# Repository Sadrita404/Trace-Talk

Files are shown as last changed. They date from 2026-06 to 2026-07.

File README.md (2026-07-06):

<div align="center">
  <table border="0" cellpadding="0" cellspacing="0">
    <tr>
      <td align="center" style="background: #ffffff; border: 1px solid #d0d7de; border-radius: 12px; padding: 16px; box-shadow: 0 4px 12px rgba(0,0,0,0.05);">
        Rough Layout For The PCB
        <div style="margin-top: 12px; font-family: -apple-system, BlinkMacSystemFont, 'Segoe UI', Helvetica, Arial, sans-serif; font-size: 13px; color: #57606a; font-weight: 500;">
      </td>
    </tr>
  </table>
</div>

| Title | Trace Talk |
| :-- | :---|
|Author |Sadrita Neogi|

## What's this?

TraceTalk is a walkie-talkie small radio  powered by a custom PCB and an ATMEGA328P (Arduino) microcontroller. It features a built-in rechargeable battery that charges with any standard USB-C cable and power brick. I also put together a custom enclosure to keep the PCB safe.
## Why I built it ?

From a very starting point, I walkie talkie due to their principle of work like the transmission between two devices without any internet connection and we are able to talk to each other. This made me fascinated, and I also wanted to make one for myself, but in general, the walkie-talkie that we see is balki and heavy so I made it pocket size, slim, walkie-talkie that can be connected via headphone and we can use it.

## How to use ?

To use the walkie-talkie, just plug any headphones with a mic into the 3.5mm jack, then flip the switch on the left side of the board and the LED will turn on. Just press and hold the button on the board to transmit your voice, and any nearby walkie-talkies will pick it up and play the audio. No pairing or setup needed.

The battery will lasts for about 4 hours( according to my calculation that I have made by going to the data sheet of each components, and this is what I approximately estimated ) and charges with any USB-C cable and power source. While it's charging, an LED near the USB port will light up, and it'll turn off once the battery is fully charged. Just a heads-up: the headphones you use can affect the audio quality, so you might want to try a few different pairs to see what works best.

## Technical Description
This project runs on an ATMEGA328P microcontroller sitting on a custom PCB (TraceTalk). It sends all the audio data through an NRF24L01 radio module. The ATMEGA328P runs at 3.3V and 8MHz, and you can program it right through the Arduino IDE. While you could technically use an external programmer like a USBTinyISP, the Arduino IDE is definitely the easiest and most straightforward way to go.

For the radio, I used the SMD version of the NRF24L01 to keep the board as small as possible. It gets a maximum range of about 100 meters.

The LiPo battery is soldered straight onto the board's battery terminals. I’d recommend picking up a battery with a 100-150mAh capacity—that’s the sweet spot for getting the best results.

<div align="center">

| | Building Process | |
| :---: | :---: | :---: |
|  |  |  |
|  |  |  |
|  |  |  |

Screenshot 2026-06-30 at 8 57 12 PM

<div align="center">
  <h2> Final Look </h2>
  <table border="0" cellpadding="10" cellspacing="0" style="border-collapse: collapse;">
    <tr>
      <!-- FRONT SIDE CARD -->
      <td align="center" valign="top" width="50%" style="background: #ffffff; border: 1px solid #d0d7de; border-radius: 12px; padding: 16px; box-shadow: 0 4px 12px rgba(0,0,0,0.05);">
        Front Side View
        <div style="margin-top: 12px; font-family: -apple-system, BlinkMacSystemFont, 'Segoe UI', Helvetica, Arial, sans-serif; font-size: 13px; color: #57606a; font-weight: 600; text-transform: uppercase; letter-spacing: 0.5px;">
          ▲ Front Side View
        </div>
      </td>
      <!-- SPACER FOR GITHUB MOBILE DEGRADATION -->
      <td width="2%">&nbsp;</td>
      <!-- BACK SIDE CARD -->
      <td align="center" valign="top" width="50%" style="background: #ffffff; border: 1px solid #d0d7de; border-radius: 12px; padding: 16px; box-shadow: 0 4px 12px rgba(0,0,0,0.05);">
        Back Side View
        <div style="margin-top: 12px; font-family: -apple-system, BlinkMacSystemFont, 'Segoe UI', Helvetica, Arial, sans-serif; font-size: 13px; color: #57606a; font-weight: 600; text-transform: uppercase; letter-spacing: 0.5px;">
          ▲ Back Side View
        </div>
      </td>
    </tr>
  </table>
</div>
</div>

<div align="center">
  <h2> Bill of Materials </h2>
</div>

| Name | Purpose | Qty | Total (USD) | Link | Distributor |
| :--- | :--- | :---: | :---: | :---: | :--- |
| PCBA SMT Assembly | SMT assembly of all SMD components | 5 | 51.93 | — | JLCPCB |
| PCB Fabrication (Trace Talk) | 2-layer PCB — the board itself | 5 | 2.00 | — | JLCPCB |
| C10,C11,C3 | 100nF 50V X7R ±10% 0805 MLCC | 25 | 0.87 | [Link](https://lcsc.com/product-detail/C476766.html) | JLCPCB |
| D1,D2 | Red Water Clear 0805 LED Indication | 22 | 0.31 | [Link](https://lcsc.com/product-detail/C434431.html) | JLCPCB |
| J1 | 1A 3.5mm Headphone Jack 30V SMD R/A | 6 | 0.63 | [Link](https://lcsc.com/product-detail/C521460.html) | JLCPCB |
| J2 | 0.3mm 1mm 5P Right Angle Top Contact FFC/FPC Connector | 6 | 0.59 | [Link](https://lcsc.com/product-detail/C262360.html) | JLCPCB |
| R1,R5,R6 | 330Ω 125mW 150V Thick Film Resistor ±5% 0805 | 25 | 0.07 | [Link](https://lcsc.com/product-detail/C25306.html) | JLCPCB |
| R2,R3 | 5.1kΩ 125mW 150V Thick Film Resistor ±1% 0805 | 10 | 0.04 | [Link](https://lcsc.com/product-detail/C27834.html) | JLCPCB |
| R10,R4 | 1kΩ 125mW 150V Thick Film Resistor ±1% 0805 | 20 | 0.09 | [Link](https://lcsc.com/product-detail/C95781.html) | JLCPCB |
| R11,R12,R13,R7,R8,R9 | 10kΩ 125mW 150V Thick Film Resistor ±1% 0805 | 30 | 0.13 | [Link](https://lcsc.com/product-detail/C17414.html) | JLCPCB |
| C1,C2,C4,C5,C6,C8 | 10V 10uF X5R ±10% 0805 MLCC | 40 | 7.11 | [Link](https://lcsc.com/product-detail/C17024.html) | JLCPCB |
| SW1 | PCM12SMTR SPDT Surface Mount Vertical Slide Switch | 5 | 6.23 | [Link](https://lcsc.com/product-detail/C221841.html) | JLCPCB |
| SW2 | PTS645 Tactile Switches 12V 50mA SMD-4P 6x6mm | 5 | 1.53 | [Link](https://lcsc.com/product-detail/C221871.html) | JLCPCB |
| U2 | MIC5205-3.3YM5-TR Fixed 3.3V 150mA Linear LDO SOT-23-5 | 5 | 1.88 | [Link](https://lcsc.com/product-detail/C37970.html) | JLCPCB |
| U3 | TP4056X-42-ESOP8 1A 4.2V Lithium Battery Charging IC | 5 | 1.00 | [Link](https://lcsc.com/product-detail/C2763448.html) | JLCPCB |
| U4 | LM358DR2G 32V Dual Operational Amplifier SOIC-8 | 5 | 0.29 | [Link](https://lcsc.com/product-detail/C7950.html) | JLCPCB |
| U5 | ATMEGA328P-AU 8-Bit AVR 20MHz TQFP-32 Microcontroller | 5 | 11.38 | [Link](https://lcsc.com/product-detail/C14877.html) | JLCPCB |
| USB1 | USB Type-C Receptacle 16P Female SMD R/A | 5 | 0.92 | [Link](https://lcsc.com/product-detail/C165948.html) | JLCPCB |
| X1 | 8MHz 33pF SMD3213-3P Ceramic Resonator | 5 | 1.92 | [Link](https://lcsc.com/product-detail/C341522.html) | JLCPCB |
| RG1 | 470kΩ 125mW 150V Thick Film Resistor ±1% 0805 | 5 | 0.02 | [Link](https://lcsc.com/product-detail/C17709.html) | JLCPCB |
| C7,C9 | 330nF 50V X7R ±10% 0805 MLCC | 20 | 0.66 | [Link](https://lcsc.com/product-detail/C1740.html) | JLCPCB |
| 3.7V 100mAH | To power the circuit | 2 | 0.00 | [Link](https://www.electropi.in/3.7v-100mah-lipo-battery-model-321225-india) | Self Sourced |
| 3d Print | For the encloser | 1 | 0.00 | [Link](https://printlegion.hackclub.com/) | #printing-legion |
| Shipping PCB	| E- Post (Cheapest) | 	- |	$10.98	| — | 	JLCPCB |
| Total | | | $100.58 | | | |

**Project Under Hack Club**

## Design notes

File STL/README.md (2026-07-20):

# Print it 5 pice for Case and Top Lid as it is for a walkie talkie and I have 5 Working PCB

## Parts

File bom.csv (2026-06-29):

Name | Purpose | Quantity | Total Cost (USD) | Link | Distributor
3d Print | For the encloser | 1 | 0.00 |  | #printing-legion
3.7V 100mAH | To power the circuit | 2 | 0.00 | https://www.electropi.in/3.7v-100mah-lipo-battery-model-321225-india | Self Sourced
PCBA SMT Assembly | SMT assembly of all SMD components | 5 | 51.93 |  | JLCPCB
PCB Fabrication (Trace Talk) | 2-layer PCB — the board itself | 5 | 2.00 |  | JLCPCB
J1 | 1A 3.5mm Headphone Jack 30V SMD R/A | 6 | 0.63 | https://lcsc.com/product-detail/C521460.html | JLCPCB
J2 | 0.3mm 1mm 5P Right Angle Top Contact FFC/FPC Connector | 6 | 0.59 | https://lcsc.com/product-detail/C262360.html | JLCPCB
R1,R5,R6 | 330Ω 125mW 150V Thick Film Resistor ±5% 0805 | 25 | 0.07 | https://lcsc.com/product-detail/C25306.html | JLCPCB
R2,R3 | 5.1kΩ 125mW 150V Thick Film Resistor ±1% 0805 | 10 | 0.04 | https://lcsc.com/product-detail/C27834.html | JLCPCB
R10,R4 | 1kΩ 125mW 150V Thick Film Resistor ±1% 0805 | 20 | 0.09 | https://lcsc.com/product-detail/C95781.html | JLCPCB
R11,R12,R13,R7,R8,R9 | 10kΩ 125mW 150V Thick Film Resistor ±1% 0805 | 30 | 0.13 | https://lcsc.com/product-detail/C17414.html | JLCPCB
RG1 | 470kΩ 125mW 150V Thick Film Resistor ±1% 0805 | 5 | 0.02 | https://lcsc.com/product-detail/C17709.html | JLCPCB
C1,C2,C4,C5,C6,C8 | 10V 10uF X5R ±10% 0805 MLCC | 40 | 7.11 | https://lcsc.com/product-detail/C17024.html | JLCPCB
SW2 | PTS645 Tactile Switches 12V 50mA SMD-4P 6x6mm | 5 | 1.53 | https://lcsc.com/product-detail/C221871.html | JLCPCB
U2 | MIC5205-3.3YM5-TR Fixed 3.3V 150mA Linear LDO SOT-23-5 | 5 | 1.88 | https://lcsc.com/product-detail/C37970.html | JLCPCB
U3 | TP4056X-42-ESOP8 1A 4.2V Lithium Battery Charging IC | 5 | 1.00 | https://lcsc.com/product-detail/C2763448.html | JLCPCB
U4 | LM358DR2G 32V Dual Operational Amplifier SOIC-8 | 5 | 0.29 | https://lcsc.com/product-detail/C7950.html | JLCPCB
U5 | ATMEGA328P-AU 8-Bit AVR 20MHz TQFP-32 Microcontroller | 5 | 11.38 | https://lcsc.com/product-detail/C14877.html | JLCPCB
USB1 | USB Type-C Receptacle 16P Female SMD R/A | 5 | 0.92 | https://lcsc.com/product-detail/C165948.html | JLCPCB
X1 | 8MHz 33pF SMD3213-3P Ceramic Resonator | 5 | 1.92 | https://lcsc.com/product-detail/C341522.html | JLCPCB
SW1 | PCM12SMTR SPDT Surface Mount Vertical Slide Switch | 5 | 6.23 | https://lcsc.com/product-detail/C221841.html | JLCPCB
C7,C9 | 330nF 50V X7R ±10% 0805 MLCC | 20 | 0.66 | https://lcsc.com/product-detail/C1740.html | JLCPCB
C10,C11,C3 | 100nF 50V X7R ±10% 0805 MLCC | 25 | 0.87 | https://lcsc.com/product-detail/C476766.html | JLCPCB
D1,D2 | Red Water Clear 0805 LED Indication | 22 | 0.31 | https://lcsc.com/product-detail/C434431.html | JLCPCB

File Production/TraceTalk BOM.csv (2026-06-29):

Comment | Designator | Footprint | LCSC
1k | R10,R4 | R_0805_2012Metric | C115316
ATmega328P-A | U5 | TQFP-32_7x7mm_P0.8mm | C14877
USB_C 31-M-12 | USB1 | USB_C_Receptacle_HRO_TYPE-C-31-M-12 | C165948
10uF | C1,C2,C4,C5,C6,C8 | C_0805_2012Metric | C17024
330nF | C7,C9 | C_0805_2012Metric | C1740
10k | R11,R12,R13,R7,R8,R9 | R_0805_2012Metric | C17414
470k | RG1 | R_0805_2012Metric | C17709
SPDT_PCM12 | SW1 | SW_SPDT_PCM12 | C221841
Pushbutton | SW2 | SW_SPST_PTS645 | C221871
330 | R1,R5,R6 | R_0805_2012Metric | C25306
ICSP | J2 | Molex_200528-0050_1x05-1MP_P1.00mm_Horizontal | C262360
TP4056 | U3 | SOIC-8-1EP_3.9x4.9mm_P1.27mm_EP2.29x3mm | C2763448
5.1k | R2,R3 | R_0805_2012Metric | C27834
Resonator 8MHz | X1 | Resonator_SMD_Murata_CSTxExxV-3Pin_3.0x1.1mm | C341522
MIC5205-3.3YM5 | U2 | SOT-23-5 | C37970
LED_0805 | D1,D2 | LED_0805_2012Metric | C434431
100nF | C10,C11,C3 | C_0805_2012Metric | C476766
Jack 3.5mm | J1 | Jack_3.5mm_PJ320D_Horizontal | C521460
LM358 | U4 | SOP-8_3.9x4.9mm_P1.27mm | C7950
NRF24L01_Breakout | U1 | NRF24L01_Mini
LiPo 100mAh | BT1 | PinSocket_1x02_P2.54mm_Vertical

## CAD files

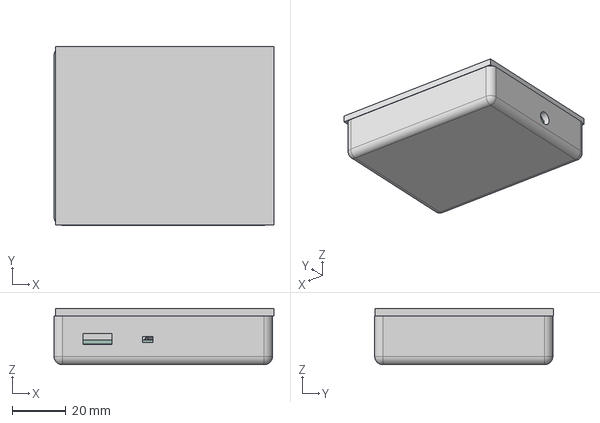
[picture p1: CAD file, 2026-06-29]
CAD/Case Assembly.step
81.8 x 66.4 x 21.0 mm
SOIC-8_3.9x4.9mm_P1.27mm
TraceTalk_PCB

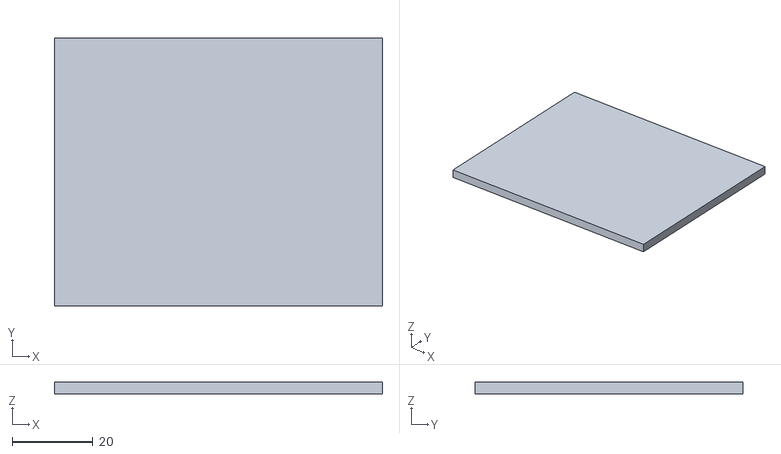
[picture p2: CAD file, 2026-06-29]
STL/Top Lid.stl
81.2 x 66.3 x 2.90

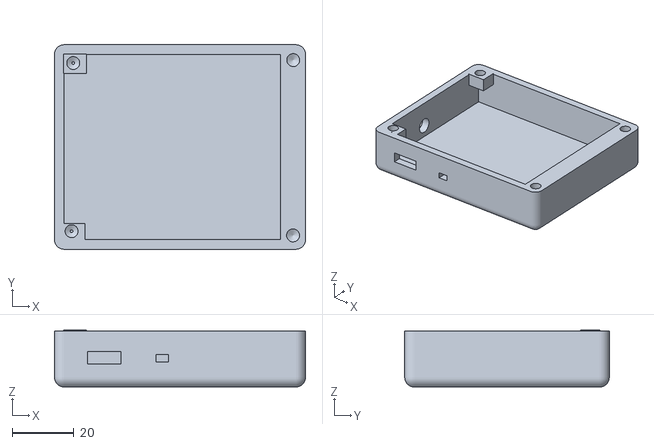
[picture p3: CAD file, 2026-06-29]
STL/Case.stl
81.2 x 66.2 x 18.4

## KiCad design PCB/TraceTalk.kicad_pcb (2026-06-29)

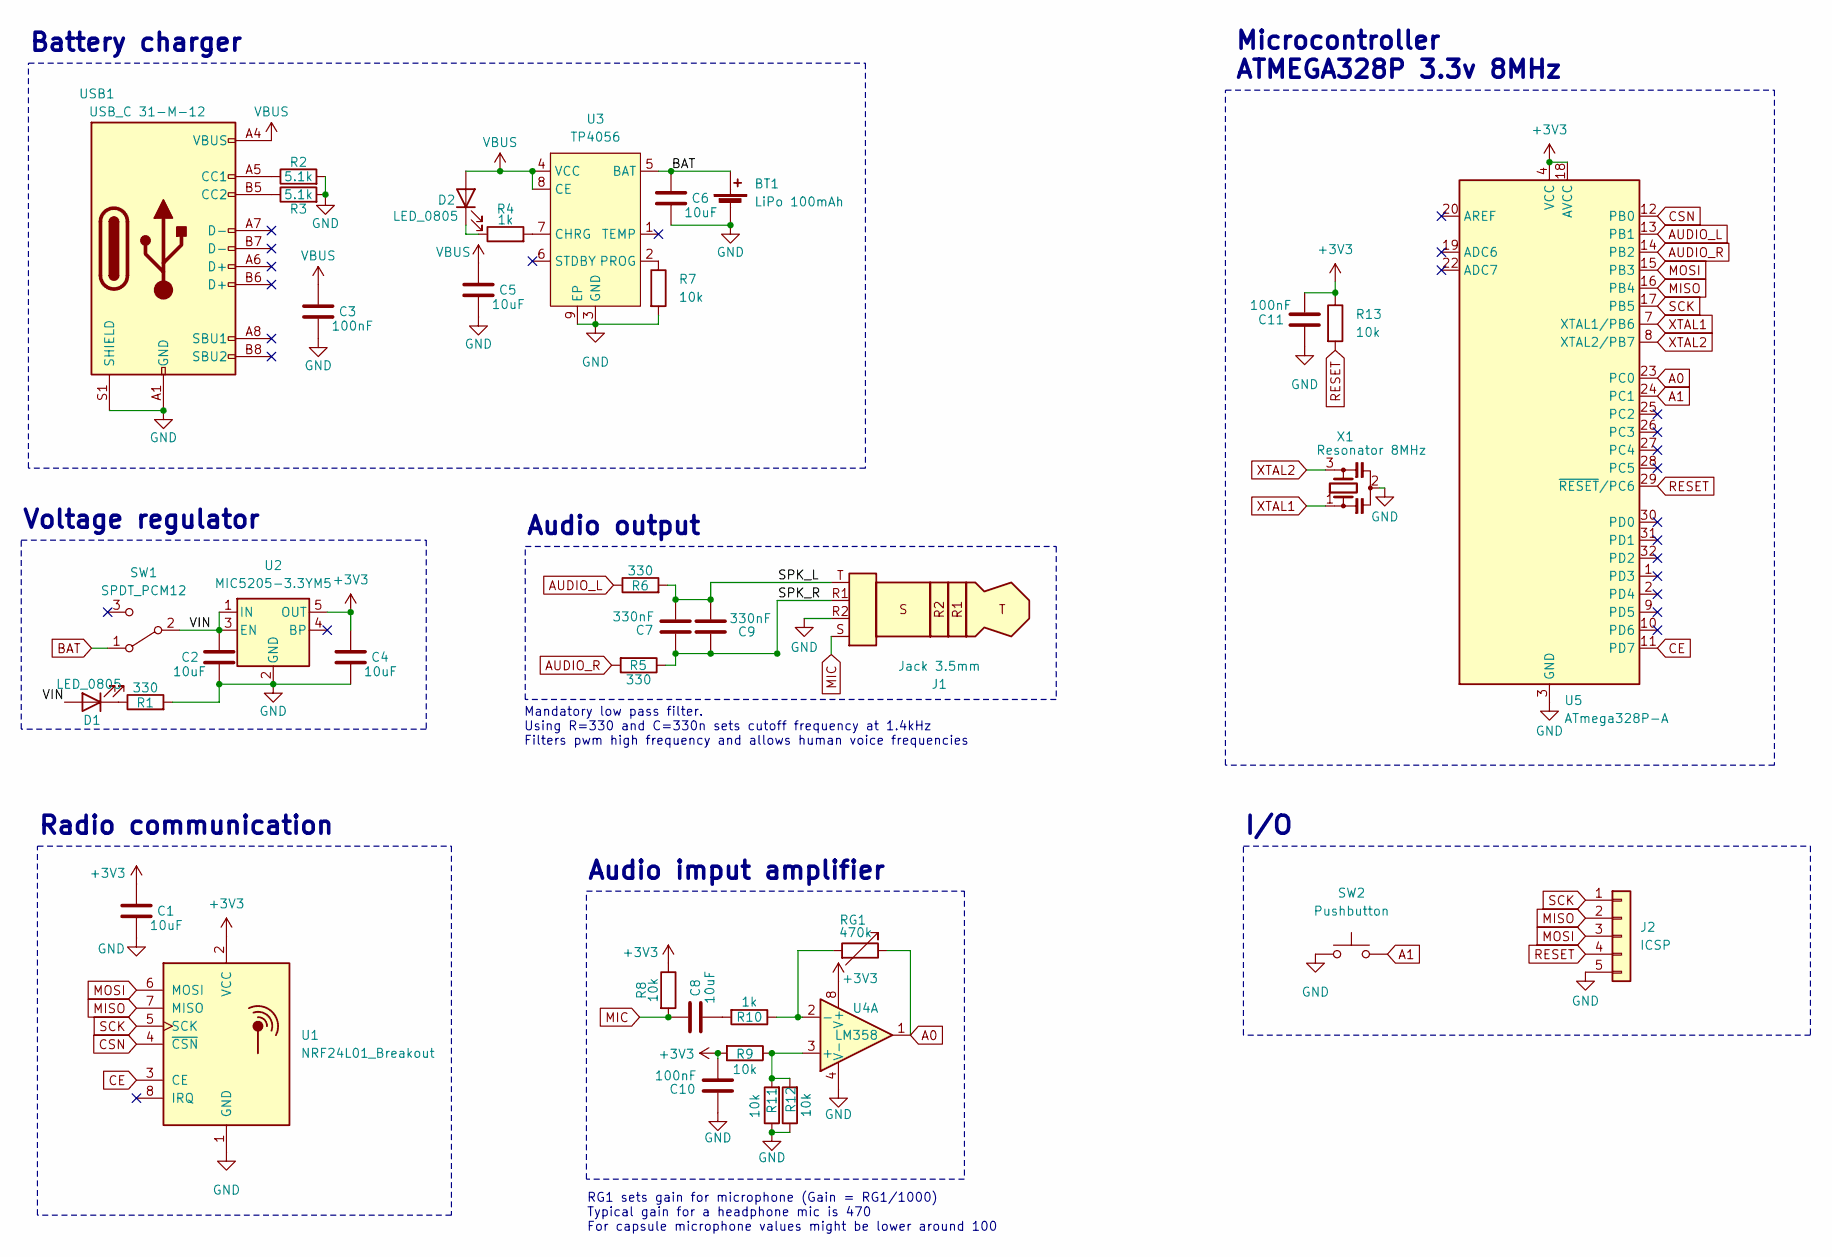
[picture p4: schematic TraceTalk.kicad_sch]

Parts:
BT1: LiPo 100mAh; PinSocket_1x02_P2.54mm_Vertical
C1, C2, C4, C5, C6, C8: 10uF; C_0805_2012Metric
C3, C10, C11: 100nF; C_0805_2012Metric
C7, C9: 330nF; C_0805_2012Metric
D1, D2: LED_0805; LED_0805_2012Metric
J1: Jack 3.5mm; Jack_3.5mm_PJ320D_Horizontal
J2: ICSP; Molex_200528-0050_1x05-1MP_P1.00mm_Horizontal
R1, R5, R6: 330; R_0805_2012Metric
R2, R3: 5.1k; R_0805_2012Metric
R4, R10: 1k; R_0805_2012Metric
R7, R8, R9, R11, R12, R13: 10k; R_0805_2012Metric
RG1: 470k; R_0805_2012Metric
SW1: SPDT_PCM12; SW_SPDT_PCM12
SW2: Pushbutton; SW_SPST_PTS645
U1: NRF24L01_Breakout; NRF24L01_Mini
U2: MIC5205-3.3YM5; SOT-23-5
U3: TP4056; SOIC-8-1EP_3.9x4.9mm_P1.27mm_EP2.29x3mm
U4: LM358; SOP-8_3.9x4.9mm_P1.27mm
U5: ATmega328P-A; TQFP-32_7x7mm_P0.8mm
USB1: USB_C 31-M-12; USB_C_Receptacle_HRO_TYPE-C-31-M-12
X1: Resonator 8MHz; Resonator_SMD_Murata_CSTxExxV-3Pin_3.0x1.1mm

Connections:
+3V3: C1.1, C4.1, C10.2, C11.2, R8.1, R9.2, R13.1, U1.2 (VCC), U2.5 (OUT), U4.8 (V+), U5.4 (VCC), U5.6 (VCC), U5.18 (AVCC)
/SPK_L: C7.2, C9.2, J1.T, R6.2
/SPK_R: C7.1, C9.1, J1.R1, R5.1
/VIN: C2.1, D1.2 (A), SW1.2 (B), U2.1 (IN), U2.3 (EN)
A0: RG1.1, U4.1, U5.23 (PC0)
A1: SW2.2, U5.24 (PC1)
AUDIO_L: R6.1, U5.13 (PB1)
AUDIO_R: R5.2, U5.14 (PB2)
BAT: BT1.1 (+), C6.1, SW1.1 (A), U3.5 (BAT)
CE: U1.3 (CE), U5.11 (PD7)
CSN: U1.4 (~CSN), U5.12 (PB0)
GND: BT1.2 (-), C1.2, C2.2, C3.2, C4.2, C5.2, C6.2, C10.1, C11.1, J1.R2, J2.5, R1.2, R2.2, R3.2, R7.2, R11.1, R12.1, SW2.1, U1.1 (GND), U2.2 (GND), U3.3 (GND), U3.9 (EP), U4.4 (V-), U5.3 (GND), U5.5 (GND), U5.21 (GND), USB1.A1 (GND), USB1.A12 (GND), USB1.B1 (GND), USB1.B12 (GND), USB1.S1 (SHIELD), X1.2
MIC: C8.1, J1.S, R8.2
MISO: J2.2, U1.7 (MISO), U5.16 (PB4)
MOSI: J2.3, U1.6 (MOSI), U5.15 (PB3)
unnamed: C8.2, R10.2
unnamed: D1.1 (K), R1.1
unnamed: D2.1 (K), R4.1
unnamed: R2.1, USB1.A5 (CC1)
unnamed: R3.1, USB1.B5 (CC2)
unnamed: R4.2, U3.7 (CHRG)
unnamed: R7.1, U3.2 (PROG)
unnamed: R10.1, RG1.2, U4.2 (-)
unnamed: R9.1, R11.2, R12.2, U4.3 (+)
RESET: J2.4, R13.2, U5.29 (~RESET/PC6)
SCK: J2.1, U1.5 (SCK), U5.17 (PB5)
VBUS: C3.1, C5.1, D2.2 (A), U3.4 (VCC), U3.8 (CE), USB1.A4 (VBUS), USB1.A9 (VBUS), USB1.B4 (VBUS), USB1.B9 (VBUS)
XTAL1: U5.7 (XTAL1/PB6), X1.1
XTAL2: U5.8 (XTAL2/PB7), X1.3

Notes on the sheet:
Battery charger
Audio imput amplifier
Mandatory low pass filter. Using R=330 and C=330n sets cutoff frequency at 1.4kHz Filters pwm high frequency and allows human voice frequencies
I/O
RG1 sets gain for microphone (Gain = RG1/1000) Typical gain for a headphone mic is 470 For capsule microphone values might be lower around 100
Radio communication
Microcontroller ATMEGA328P 3.3v 8MHz
Audio output
Voltage regulator

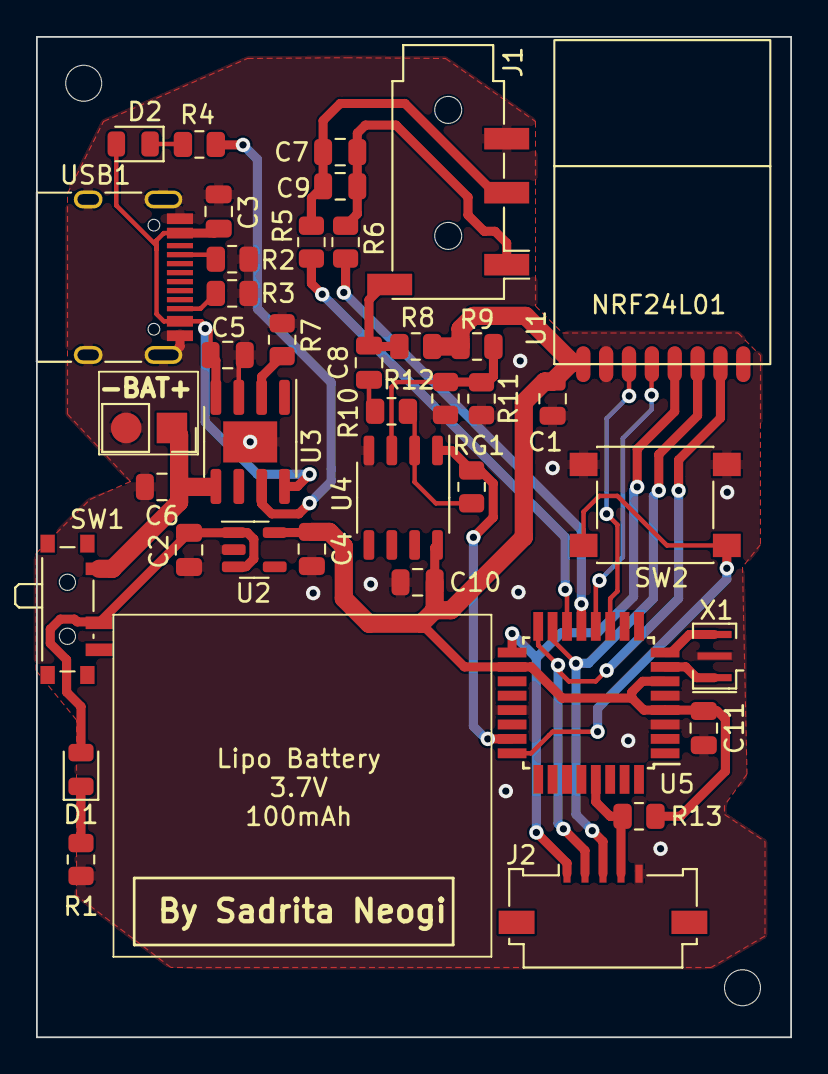
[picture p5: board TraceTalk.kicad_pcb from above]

Board: 2 copper layers, 41.9 x 55.6 mm, 39 parts (0 on the bottom side), 29 nets.

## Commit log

2026-06-29 kicad file added
    [TraceTalk.kicad_pcb, TraceTalk.kicad_sch]
2026-06-29 jlc production
    [TraceTalk BOM.csv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]
